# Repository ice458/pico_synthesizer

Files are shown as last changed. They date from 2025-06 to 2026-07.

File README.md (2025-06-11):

# Pico Synthesizer

A synthesizer project for the Raspberry Pi Pico 2.  
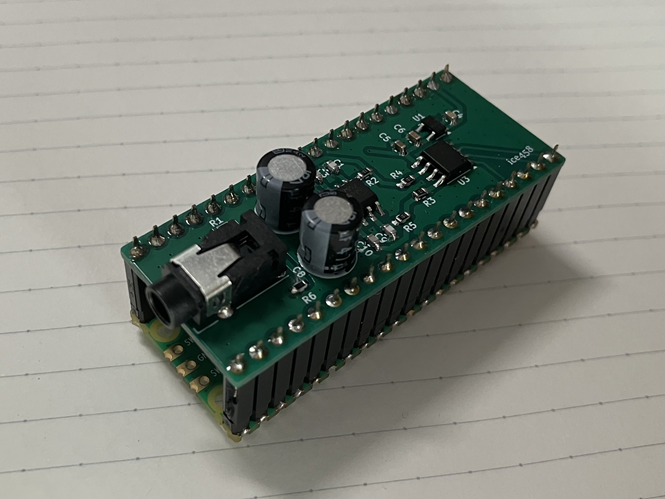
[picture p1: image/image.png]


## Description

This project aims to create a functional 16-channel polyphonic synthesizer with a maximum of 20 voices running on the Raspberry Pi Pico 2 microcontroller. It includes various features like multiple waveform generation, envelope control, MIDI input processing, and more.

## Features

*   Polyphonic sound generation
*   Multiple waveforms (Sine, Sawtooth, Triangle, Square, Noise)
*   ADSR envelope
*   MIDI input processing (Note On/Off, Pitch Bend, CC messages)
*   PCM drum sample playback
*   Reverb effect (Master output)
*   Master volume and DC cut filter

## Tools

The `tools` directory contains Python scripts used to generate various data tables and C header files required by the synthesizer:

*   `wave_table.py`: Generates waveform tables and MIDI note-to-frequency increment tables.
*   `pitch_bend_table_interpolated.py`: Generates tables for pitch bend calculations.
*   `drum_table.py`: Processes a WAV file containing drum samples and converts them into C arrays for PCM playback.
*   `pan_table.py`: Generates tables for pan calculations.

## License

This project is licensed under the MIT License. See the `LICENSE` file for more details.

Additionally, the drum samples provided in `tools/drum/drum.wav` were generated using the `MuseScore_General.sf2` soundfont. The license for `MuseScore_General.sf2` can be found in `tools/drum/MuseScore_General_License.md`.

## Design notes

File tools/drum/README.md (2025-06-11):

# Drum Samples

The `drum.wav` file in this directory was generated from `drum.mid` using the `MuseScore_General.sf2` soundfont.

The license for `MuseScore_General.sf2` can be found in `MuseScore_General_License.md`.

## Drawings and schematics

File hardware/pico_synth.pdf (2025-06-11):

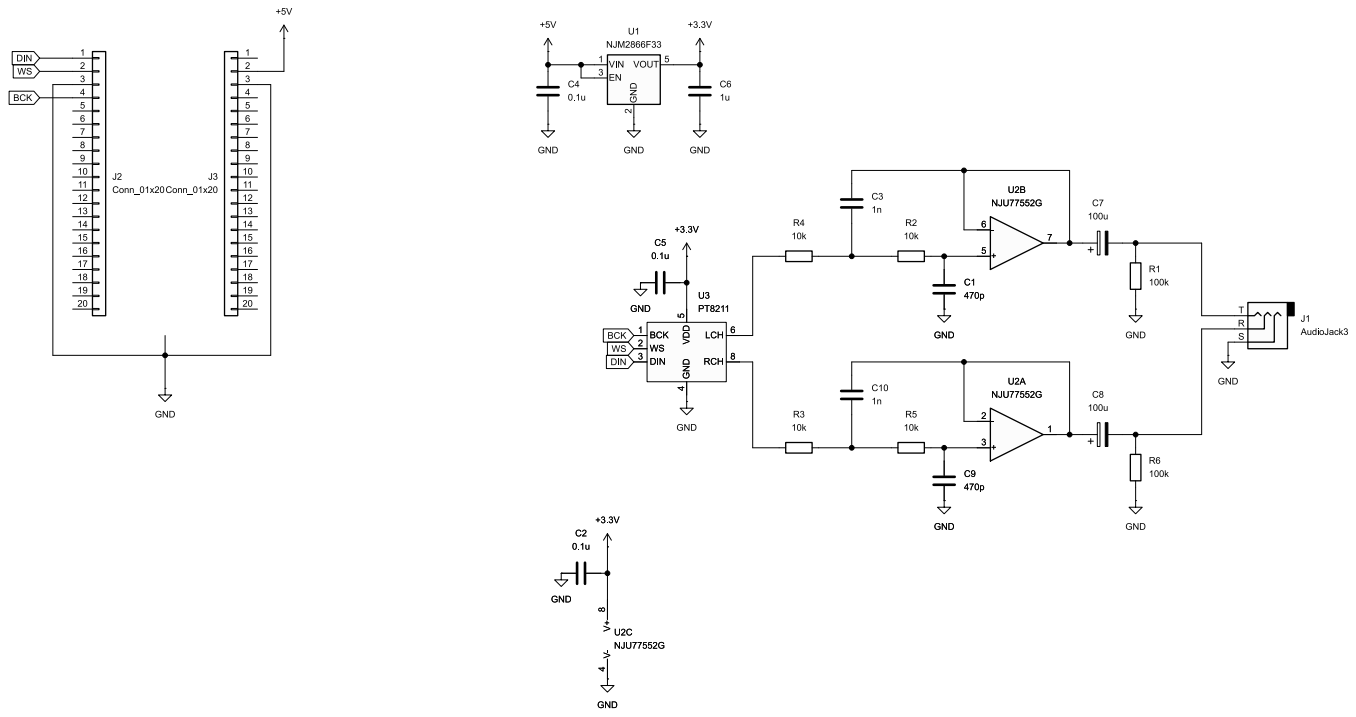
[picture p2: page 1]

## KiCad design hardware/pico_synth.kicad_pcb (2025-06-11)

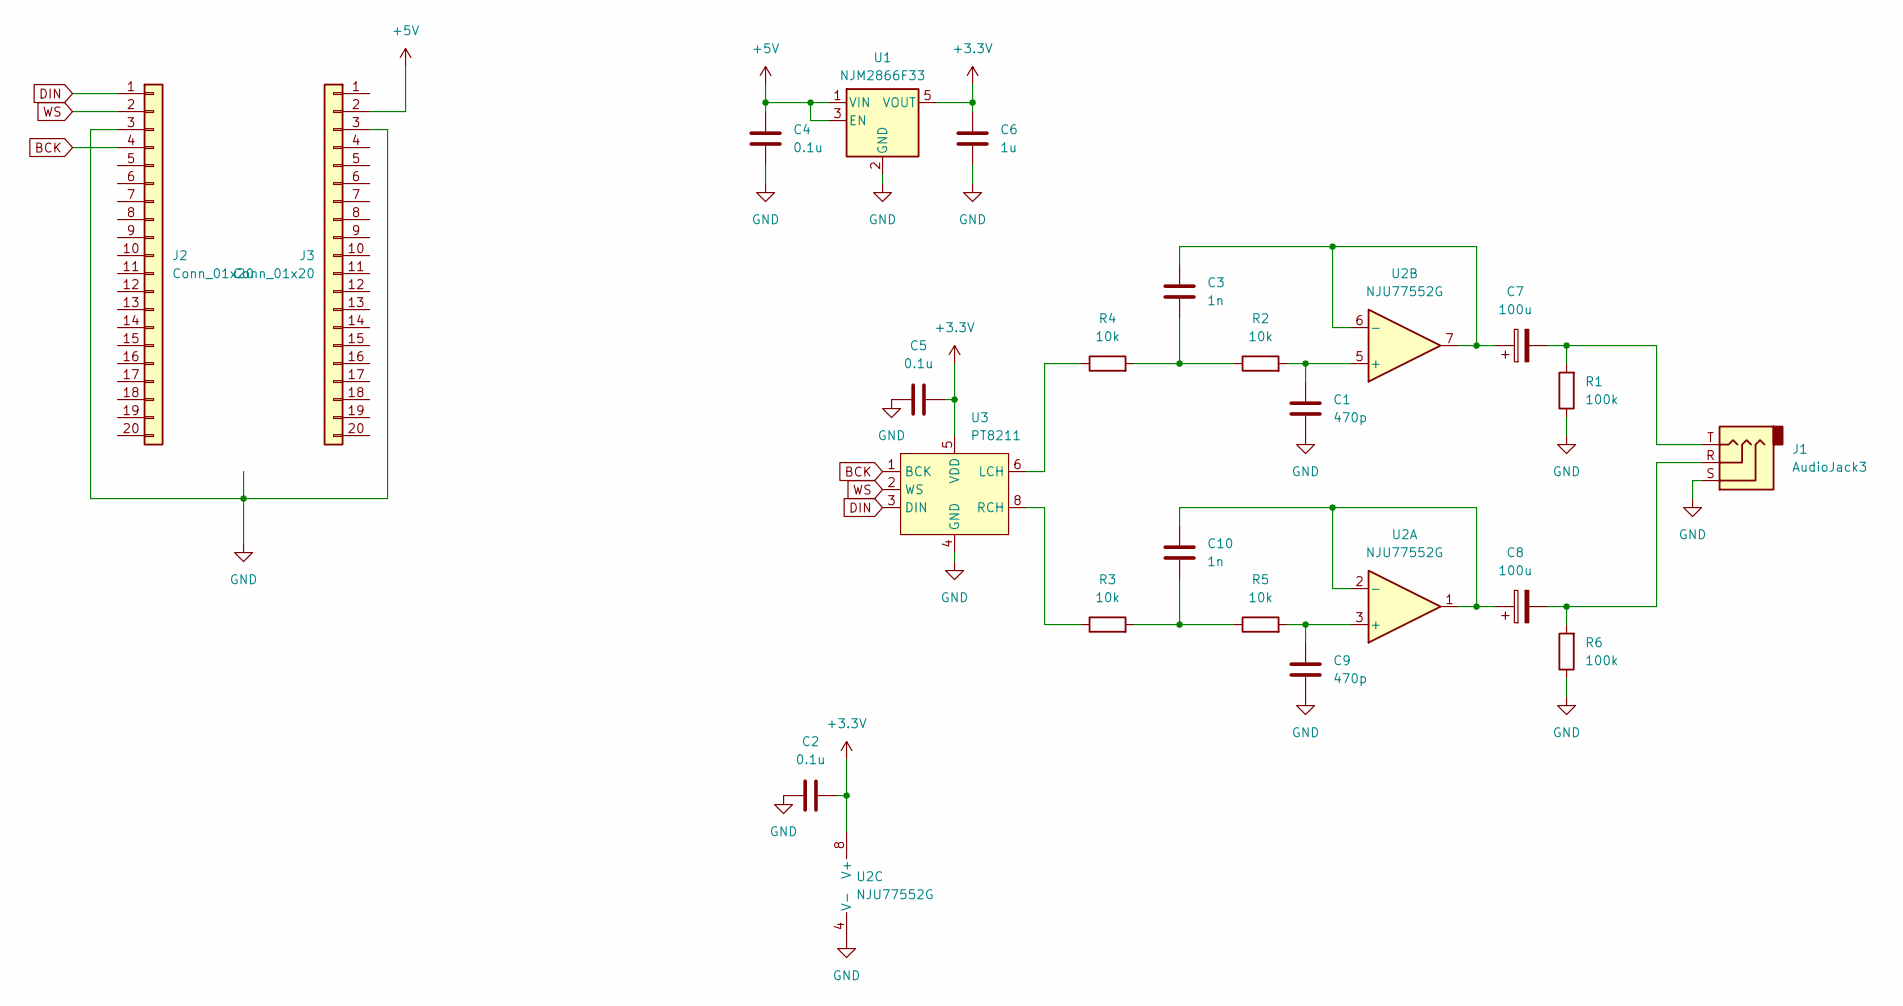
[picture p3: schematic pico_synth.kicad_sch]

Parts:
C1, C9: 470p; C_0603_1608Metric
C2, C4, C5: 0.1u; C_0603_1608Metric
C3, C10: 1n; C_0603_1608Metric
C6: 1u; C_0603_1608Metric
C7, C8: 100u; CP_Radial_D6.3mm_P2.50mm
J1: AudioJack3; Jack_3.5mm_Switronic_ST-005-G_horizontal
J2, J3: Conn_01x20; PinHeader_1x20_P2.54mm_Vertical
R1, R6: 100k; R_0603_1608Metric
R2, R3, R4, R5: 10k; R_0603_1608Metric
U1: NJM2866F33; SOT-23-5
U2: NJU77552G; SO-8_3.9x4.9mm_P1.27mm
U3: PT8211; SO-8_3.9x4.9mm_P1.27mm

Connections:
+3.3V: C2.2, C5.2, C6.1, U1.5 (VOUT), U2.8 (V+), U3.5 (VDD)
+5V: C4.1, J3.2, U1.1 (VIN), U1.3 (EN)
BCK: J2.4, U3.1 (BCK)
DIN: J2.1, U3.3 (DIN)
GND: C1.2, C2.1, C4.2, C5.1, C6.2, C9.2, J1.S, J2.3, J3.3, R1.1, R6.1, U1.2 (GND), U2.4 (V-), U3.4 (GND)
unnamed: C3.2, R2.1, R4.2
unnamed: C7.2, J1.T, R1.2
unnamed: C8.2, J1.R, R6.2
unnamed: C10.2, R3.2, R5.1
unnamed: C9.1, R5.2, U2.3 (+)
unnamed: C8.1, C10.1, U2.1, U2.2 (-)
unnamed: C1.1, R2.2, U2.5 (+)
unnamed: C3.1, C7.1, U2.6 (-), U2.7
unnamed: R4.1, U3.6 (LCH)
unnamed: R3.1, U3.8 (RCH)
WS: J2.2, U3.2 (WS)

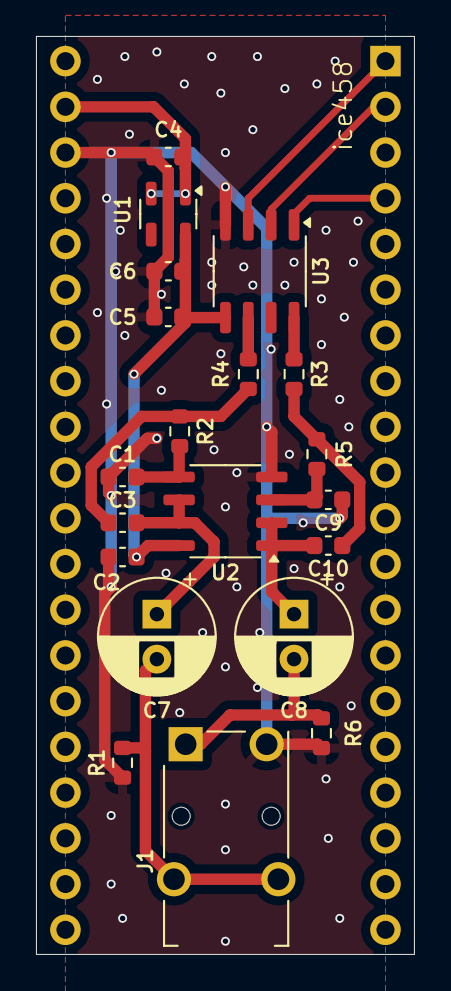
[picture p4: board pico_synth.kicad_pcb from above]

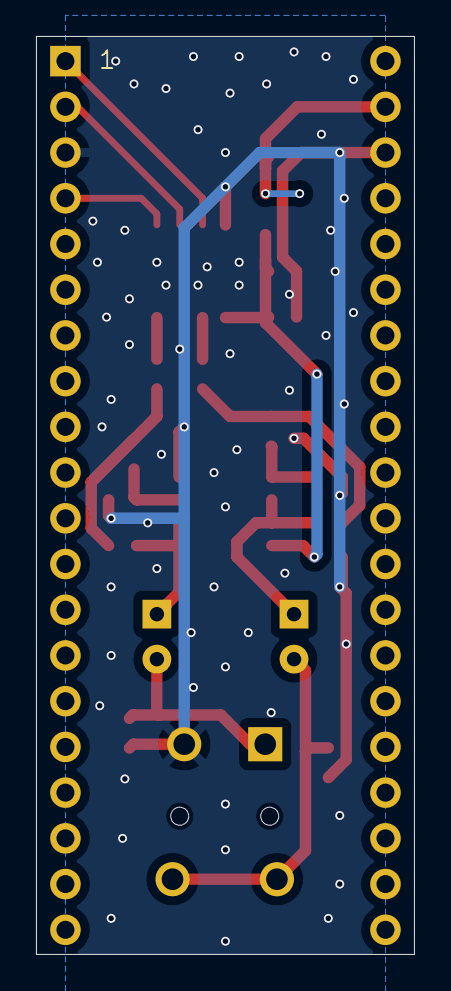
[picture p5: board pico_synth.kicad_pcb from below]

Board: 2 copper layers, 21.0 x 51.0 mm, 22 parts (2 on the bottom side), 16 nets.

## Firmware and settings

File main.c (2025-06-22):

#include <stdio.h>
#include "pico/stdlib.h"
#include "hardware/pio.h"
#include "hardware/clocks.h"
#include "hardware/uart.h"
#include "hardware/vreg.h"
#include <math.h>

#include "audio_dac.pio.h"
#include "synthesizer.h"
#include "midi.h"

#define PLL_SYS_KHZ 380 * 1000

// UART(for debugging)
#define UART_ID uart0
#define BAUD_RATE 115200
#define UART_TX_PIN 12
#define UART_RX_PIN 13

bool timer_callback(struct repeating_timer *t)
{
    gpio_put(15, 1); // measure processing time
    stereo_t data = master(voice_state);
    pio_sm_put_blocking(pio0, 0, data.u32);
    gpio_put(15, 0); // end of processing time measurement
    return true;
}

int main()
{
    set_sys_clock_48mhz();
    sleep_ms(2);

    stdio_init_all();
    board_init();
    tusb_init();

    vreg_set_voltage(VREG_VOLTAGE_1_30);
    sleep_ms(2);
    set_sys_clock_khz(PLL_SYS_KHZ, true);
    sleep_ms(2);

    uart_init(UART_ID, BAUD_RATE);
    gpio_set_function(UART_TX_PIN, GPIO_FUNC_UART);
    gpio_set_function(UART_RX_PIN, GPIO_FUNC_UART);

    // GPIO 15 for measuring processing time
    gpio_init(15);
    gpio_set_dir(15, GPIO_OUT);
    gpio_put(15, 0);

    // LED initialization
    gpio_init(PICO_DEFAULT_LED_PIN);
    gpio_set_dir(PICO_DEFAULT_LED_PIN, GPIO_OUT);
    gpio_put(PICO_DEFAULT_LED_PIN, 0);

    // PIO initialization
    PIO pio = pio0;
    uint offset = pio_add_program(pio, &LSBJ16bit_program);
    uint sm = 0;
    uint clkdiv = 100;
    LSBJ16bit_program_init(pio, sm, offset, clkdiv, 0);

    // Repeating timer for audio processing
    // Timer interval is set to 25 microseconds (40 kHz sample rate)
    struct repeating_timer timer;
    add_repeating_timer_us(-25, &timer_callback, NULL, &timer);

    // Initialize synthesizer and MIDI buffer
    midi_buffer_init();
    init_master();

    printf("hello\n");
    while (true)
    {
        tud_task();
        midi_task();
        synthesizer_task();
    }
}

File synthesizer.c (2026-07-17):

/*
Synthesizer
├─ synthesizer.h
│    ├─ enum definitions
│    │    ├─ wave_type_t (SIN, SQU, SAW, TRI, NOISE)
│    │    ├─ env_state_t (ATTACK, DECAY, SUSTAIN, RELEASE, IDLE)
│    │    └─ sweep_type_t (SWEEP_NONE, SWEEP_UP, SWEEP_DOWN)
│    ├─ struct definitions
│    │    ├─ tone_t
│    │    │    ├─ osc1 (wave_type_t type)
│    │    │    ├─ rm (int8_t freq_rate, int8_t rm_gain)
│    │    │    ├─ sweep (sweep_type_t type, int8_t speed)
│    │    │    ├─ env (int8_t attack_time, decay_time, sustain_level, sustain_rate, release_time)
│    │    │    └─ output_gain (fp_t)
│    │    ├─ voice_state_t
│    │    │    ├─ assigned_channel_num (int8_t)
│    │    │    ├─ tone (tone_t)
│    │    │    ├─ note (int8_t)
│    │    │    ├─ velocity (int8_t)
│    │    │    ├─ osc1 (wave_type_t type, q8_t increment, q8_t read_pointer)
│    │    │    ├─ osc2 (q8_t increment, q8_t read_pointer)
│    │    │    ├─ pb (q8_t factor)
│    │    │    ├─ env (fp_t amplitude, env_state_t state, uint32_t counter, bool is_note_off_received)
│    │    │    ├─ dc_cut (fp_t prev_out, fp_t prev_in)
│    │    │    └─ amplitude (fp_t)
│    │    └─ ch_state_t
│    │         ├─ tone (tone_t)
│    │         ├─ pitch_bend (int8_t sensitivity, uint16_t range)
│    │         ├─ volume (fp_t)
│    │         ├─ expression (uint8_t)
│    │         ├─ mod (uint8_t depth, uint8_t freq)
│    │         ├─ is_hold_on (bool)
│    │         ├─ pan (uint8_t)
│    │         └─ nrpn_rpn (param_type_t param_type, uint8_t nrpn_msb, uint8_t nrpn_lsb, uint8_t rpn_msb, uint8_t rpn_lsb, uint8_t data_msb, uint8_t data_lsb, bool has_lsb)
│    ├─ include "tone.h"
│    ├─ global variable definitions
│    │    ├─ voice_state_t voice_state[MAX_VOICE_NUM]
│    │    ├─ ch_state_t channel_state[MAX_CHANNEL_NUM]
│    │    ├─ master_state_t master_state
│    │    └─ reverb_state_t reverb_state
│    └─ function declarations
│         ├─ set_voice_state
│         ├─ voice
│         ├─ init_channel
│         ├─ init_master
│         ├─ init_reverb
│         ├─ note_on
│         ├─ note_off
│         ├─ channel
│         ├─ reverb
│         ├─ master
│         └─ synthesizer_task
│
├─ tone.c (tone_gm definition)
│
├─ pitch_bend_table.h (pitch_bend_factors_all definition)
│
├─ wave_table.h (wave_table definitions)
│
├─ fp.h (fixed-point arithmetic definitions)
│
├─ midi.h (MIDI buffer and event handling)
│
├─ synthesizer.c
│    ├─ global variables definitions
│    │    ├─ voice_state_t voice_state[MAX_VOICE_NUM]
│    │    ├─ ch_state_t channel_state[MAX_CHANNEL_NUM]
│    │    ├─ master_state_t master_state
│    │    └─ reverb_state_t reverb_state
│    ├─ function definitions
│    │    ├─ set_voice_state(voice_state_t *vs, tone_t *tone, int8_t ch, int8_t note, int8_t velocity)
│    │    ├─ voice(voice_state_t *vs)
│    │    ├─ init_channel(int8_t ch_to_init)
│    │    ├─ init_master()
│    │    ├─ init_reverb()
│    │    ├─ note_on(midi_t *midi, voice_state_t *vs)
│    │    ├─ note_off(midi_t *midi, voice_state_t *vs)
│    │    ├─ channel(voice_state_t *vs, int8_t ch)
│    │    ├─ reverb(stereo_t input)
│    │    ├─ master(voice_state_t *vs)
│    │    └─ synthesizer_task()
*/

#include "synthesizer.h"
#include "pan_table.h"

voice_state_t voice_state[MAX_VOICE_NUM];
ch_state_t channel_state[MAX_CHANNEL_NUM];
master_state_t master_state;
reverb_state_t reverb_state;

static inline q8_t get_interpolated_pitch_bend_factor(int8_t sensitivity_idx, uint16_t bend_value_midi)
{
    if (sensitivity_idx < 0 || sensitivity_idx >= 25)
    {
        sensitivity_idx = 2; // Default to +/- 2 semitones if out of range
    }

    if (PITCH_BEND_INTERPOLATED_TABLE_SIZE == 0)
        return float_to_q8(1.0f);
    if (PITCH_BEND_INTERPOLATED_TABLE_SIZE == 1)
        return pitch_bend_factors_interpolated[sensitivity_idx][0];

    const uint32_t original_table_max_input = PITCH_BEND_ORIGINAL_TABLE_SIZE - 1;
    const uint32_t interpolated_table_max_idx = PITCH_BEND_INTERPOLATED_TABLE_SIZE - 1;

    if (original_table_max_input == 0)
    {
        return pitch_bend_factors_interpolated[sensitivity_idx][0];
    }
    if (bend_value_midi >= original_table_max_input)
    {
        return pitch_bend_factors_interpolated[sensitivity_idx][interpolated_table_max_idx];
    }

    uint32_t scaled_numerator = (uint32_t)bend_value_midi * interpolated_table_max_idx;

    int idx1 = scaled_numerator / original_table_max_input;

    uint32_t remainder = scaled_numerator % original_table_max_input;
    uint8_t fraction_u8 = (uint8_t)((remainder * 256U) / original_table_max_input);

    int idx2 = idx1 + 1;

    q8_t val1 = pitch_bend_factors_interpolated[sensitivity_idx][idx1];
    q8_t val2 = pitch_bend_factors_interpolated[sensitivity_idx][idx2];

    int32_t diff = (int32_t)val2 - (int32_t)val1;
    int32_t term = (diff * fraction_u8) >> 8;

    return val1 + (q8_t)term;
}
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

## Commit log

2025-06-22 ノイズ対策でボイスのLPFをコメントアウト
2025-06-22 PBバク修正
2025-06-22 RPN NRPNでMSBのみを受信した場合にも値を処理するように修正
2025-06-28 ADPCM対応
2026-07-17 ピッチベンド幅変更に応答しない問題を修正
